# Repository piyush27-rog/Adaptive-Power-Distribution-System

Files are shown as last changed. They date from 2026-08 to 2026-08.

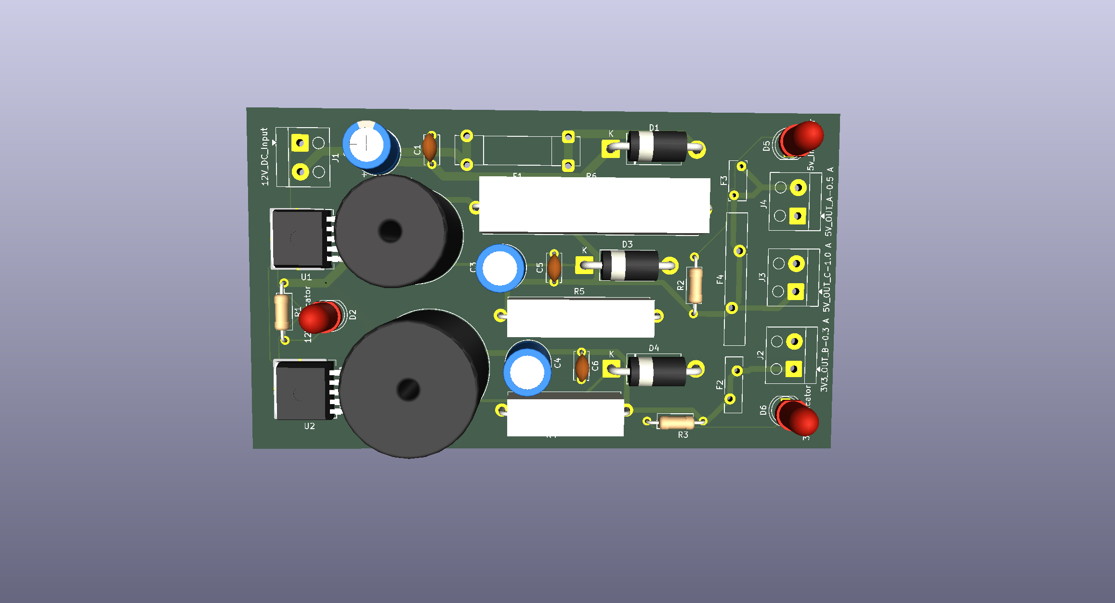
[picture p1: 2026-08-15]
Adaptive-Power-Distribution-System/Images/Adaptive_Power_Distribution_System.png

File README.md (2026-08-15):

# Adaptive Power Distribution System

A 12 V DC power distribution system designed to provide regulated **5 V and 3.3 V outputs** for multiple loads, with input protection and individual output protection.

## Key Specifications

| Parameter | Specification |
|---|---|
| Input | 12 V DC |
| 5 V Output | 5 V / 1.5 A total |
| 3.3 V Output | 3.3 V / 0.3 A |
| Regulators | LM2596S-5 / LM2596S-3.3 |
| Input Protection | 3 A Fuse + Reverse Polarity Protection |
| Output Protection | Individual Polyfuses |
| Simulation | NI Multisim |
| PCB Design | KiCad |

## Highlights

- Dual regulated power rails: **5 V and 3.3 V**
- Reverse-polarity and overcurrent protection
- Individual protected output branches
- Custom schematic and PCB layout
- Simulation and waveform verification
- Engineering calculations and BOM included

## Project Files

- **Multisim** — Circuit simulation
- **KiCad** — Schematic and PCB files
- **Documentation** — BOM, engineering calculations and design explanation
- **Images** — Schematic and PCB views
- **Simulation** — Simulation results

## Tools

**NI Multisim · KiCad**

## Author

**Piyush Thote**

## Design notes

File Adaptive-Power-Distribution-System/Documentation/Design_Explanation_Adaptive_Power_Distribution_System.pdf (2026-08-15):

Adaptive Power Distribution System — Design Explanation

# DESIGN EXPLANATION

## Adaptive Power Distribution System

12 V DC Input • Regulated 5 V & 3.3 V Outputs

### 1. Design Objective

The objective of the Adaptive Power Distribution System is to accept a 12 V DC input and distribute regulated low-voltage power to multiple loads. The design provides a regulated 5 V rail for two loads and a regulated 3.3 V rail for one load, while incorporating input protection, reverse-polarity protection, current protection, power indication and load/status indication.

The design was developed as a complete electronics system: the circuit was simulated in Multisim, the schematic and PCB were developed in KiCad, and the component ratings and power requirements were considered during the design process.

### 2. Overall Circuit Architecture

The system is divided into the following functional blocks:

Block | Function
12 V DC Input | Accepts the external 12 V supply through the input connector.
Input Protection | Provides input overcurrent protection and reverse-polarity protection.
Input Filtering / Energy Storage | Uses bulk and high-frequency capacitors on the protected input rail.
5 V Buck Converter | LM2596S-5.0 generates the regulated 5 V supply.
3.3 V Buck Converter | LM2596S-3.3 generates the regulated 3.3 V supply.
Output Protection | Polyfuses provide resettable overcurrent protection on the output branches.
Power / Load Indicators | LED indicator branches provide visual indication for the input/output rails.
Output Connectors | Distribute the regulated rails to the specified loads.

Power flows from the 12 V input through the input protection stage and then to both buck-converter stages. The converters independently generate the required 5 V and 3.3 V rails. Each output is then distributed through protected branches to the corresponding load connectors.

### 3. Input Protection and Power Entry

### 3.1 Input overcurrent protection

A 3 A fuse is placed in series with the 12 V input. Its purpose is to interrupt the input supply in the event of an abnormal overcurrent condition and to protect the downstream circuitry.

### 3.2 Reverse-polarity protection

A 1N5822 Schottky diode is used in series with the input path for reverse-polarity protection. Under normal polarity the diode permits the supply to reach the protected 12 V rail; if the supply polarity is reversed, the diode blocks the reverse connection.

### 3.3 Input filtering and energy storage

The protected input rail includes a 470 µF bulk capacitor and a 100 nF bypass capacitor. The bulk capacitor provides local energy storage and helps reduce input-voltage variation, while the 100 nF capacitor provides high-frequency bypassing.

### 4. Voltage Regulation Approach

Two independent buck-converter stages are used rather than a single regulator because the system requires two different regulated output voltages.

Stage | Regulator | Output | Required load
5 V stage | LM2596S-5.0 | 5.0 V | 0.5 A + 1.0 A = 1.5 A
3.3 V stage | LM2596S-3.3 | 3.3 V | 0.3 A

The buck topology is appropriate because both required output voltages are lower than the 12 V input. A switching regulator is also better suited to the specified power level than a linear regulator because it can reduce conversion power dissipation.

### 5. Buck-Converter Power Stage

Each LM2596 stage uses the required switching-converter elements: the regulator, a 68 µH inductor, a 1N5822 Schottky diode and a 330 µF output capacitor. The output capacitor supports transient load demand and helps stabilize the regulated rail.

The switching nodes were treated as high-frequency nodes during PCB routing. Their traces were kept short to reduce unnecessary loop area. The higher-current 12 V, 5 V and 3.3 V distribution paths were assigned wider PCB traces, while small-signal connections use narrower traces.

### 6. Output Power Distribution

The 5 V rail supplies two specified loads: Load A at 500 mA and Load C at 1 A. Their combined nominal current is therefore 1.5 A. The 3.3 V rail supplies Load B at 300 mA.

Output | Loads | Total current | Nominal output power
5 V | 500 mA + 1 A | 1.50 A | 7.50 W

3.3 V | 300 mA | 0.30 A | 0.99 W
Total | All specified loads | — | 8.49 W

### 7. Output Current Protection

Resettable polyfuses are placed before the output connectors. This creates separately protected output branches rather than relying only on a common input fuse. The selected branches are intended for the specified 5 V/0.5 A, 5 V/1 A and 3.3 V/0.3 A loads.

The use of separate protected branches improves fault isolation: an abnormal condition on one output branch can be limited without requiring the entire distribution system to be disconnected. The exact hold and trip characteristics depend on the final polyfuse part selected and its operating temperature.

### 8. Power and Load Indication

LED indicator branches are included to provide visual status information for the available rails. Series resistors limit LED current. The indicators are intentionally treated as low-power branches and therefore use narrow signal traces compared with the main power rails.

### 9. Schematic Design Decisions

Decision | Reason
Two independent buck stages | Required 5 V and 3.3 V outputs are independently regulated.
Schottky input diode | Provides simple reverse-polarity protection with relatively low forward drop.
3 A input fuse | Provides input overcurrent protection with margin over the expected normal input current.
470 µF input capacitor | Provides bulk energy storage and input smoothing.
100 nF bypass capacitors | Provides high-frequency local bypassing.
330 µF output capacitors | Supports output transients and reduces output ripple.
Output polyfuses | Provides resettable branch-level current protection.
Separate output connectors | Allows independent distribution of the required rails to loads.

### 10. PCB Architecture

The PCB was organized so that the power-entry and protection section is separated from the two converter stages and the output connectors. The inductors, Schottky diodes and output capacitors are kept close to their respective LM2596 stages to keep the switching paths compact.

High-current power nets were routed with wider traces. The 12 V main path uses approximately 1.5 mm, the 5 V main path approximately 1.0–1.5 mm depending on the branch, and the 3.3 V main path approximately 1.0 mm. Small signal paths use approximately 0.2–0.25 mm. A copper ground plane is used to provide a low-impedance return path and simplify ground distribution.

The completed PCB concept also includes output polyfuses, output connectors and status indicators, providing a compact power-distribution arrangement rather than a collection of independent regulator circuits.

### 11. Simulation Approach

The circuit was simulated in Multisim under the specified resistive load conditions. The load resistances were calculated from R = V/I: 10 Ω for 5 V/500 mA, 5 Ω for 5 V/1 A, and 11 Ω for 3.3 V/300 mA.

Voltage probes and current measurements were used to verify the input and regulated output behavior. An oscilloscope was also used to observe the output waveform and settling behavior. The simulation confirmed that the converter stages reach the intended regulated output levels under the modeled load conditions.

During simulation, a long real-time observation was initially noticed at the output measurement display. The oscilloscope measurement showed the electrical response occurring on a much shorter simulation-time scale, so the long timer observation was treated as a simulation/display timing issue rather than as a physical one-minute-plus regulator startup requirement.

### 12. Design Verification

Item | Target / requirement | Design implementation
Input voltage | 12 V DC | 12 V DC input connector
5 V output | 5 V regulated | LM2596S-5.0
3.3 V output | 3.3 V regulated | LM2596S-3.3
5 V load capacity | 1.5 A total | Dedicated 5 V buck stage
3.3 V load capacity | 0.3 A | Dedicated 3.3 V buck stage
Input protection | Required | 3 A fuse + 1N5822
Current protection | Required | Output polyfuses
Power indication | Required | LED indicators
Safe power distribution | Required | Protected individual output branches

### 13. Limitations

- Reverse-polarity protection using a series Schottky diode introduces a forward-voltage drop and associated power loss.
- Exact converter efficiency and thermal performance depend on the selected LM2596 implementation, inductor, diode, capacitors, PCB copper area and operating temperature.

- Polyfuse behavior is temperature- and time-dependent; the final part's hold/trip curves should be checked against the intended loads.
- The Multisim model does not replace hardware validation. Real measurements should be performed for ripple, efficiency, temperature rise, startup behavior and protection response.
- The design is intended for the specified low-voltage loads; higher loads should not be connected without rechecking regulator current capability, thermal performance, traces, connectors and protection ratings.

### 14. Possible Improvements

- Replace the series reverse-polarity diode with an ideal-diode MOSFET arrangement to reduce input voltage drop and conduction loss.
- Use regulators with integrated thermal/current protection and optimize the power-stage components using the exact regulator datasheet recommendations.
- Add dedicated input and output transient protection such as TVS protection if the real operating environment contains significant surges or cable transients.
- Add test points for 12 V protected, 5 V, 3.3 V and GND to simplify production testing and debugging.
- Add mounting holes and mechanical keep-outs for enclosure integration.
- Validate the finished PCB experimentally using electronic loads and a thermal camera or thermocouple, then update the efficiency and thermal calculations with measured data.
- Consider separate status indicators for each protected output branch if more detailed load-status information is required.

### 15. Conclusion

The final design implements a compact 12 V DC power-distribution system with independently regulated 5 V and 3.3 V outputs. The architecture combines buck conversion, input protection, reverse-polarity protection, branch-level resettable current protection, filtering, indication and a dedicated PCB layout. The calculated full-load output requirement is 8.49 W, consisting of 7.50 W on the 5 V rail and 0.99 W on the 3.3 V rail. The completed schematic, Multisim simulation and PCB were developed around these requirements.

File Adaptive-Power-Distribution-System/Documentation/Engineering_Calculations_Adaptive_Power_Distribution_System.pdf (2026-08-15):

Adaptive Power Distribution System — Engineering Calculations

# ENGINEERING CALCULATIONS

## Adaptive Power Distribution System

12 V DC Input • Regulated 5 V & 3.3 V Outputs

### 1. Purpose and Design Basis

Purpose. This document presents the calculations used to size the loads, determine output power and current, assess regulator requirements, justify protection, and consider power loss and thermal behavior.

Assessment basis. The assessment specifies a 12 V DC input, regulated 5 V and 3.3 V outputs, Load A = 5 V/500 mA, Load B = 3.3 V/300 mA, and Load C = 5 V/1 A. It also asks for calculations covering current, power, losses, regulator requirements and thermal considerations.

Implemented design. The completed design uses LM2596S-5.0 and LM2596S-3.3 buck-converter stages. The Multisim loads are represented by 10 Ω, 11 Ω and 5 Ω resistors.

### 2. Design Input and Load Requirements

Load/Rail | Voltage | Current | Equivalent R | Power
Load A | 5.0 V | 0.50 A | 10 Ω | 2.50 W
Load B | 3.3 V | 0.30 A | 11 Ω | 0.99 W
Load C | 5.0 V | 1.00 A | 5 Ω | 5.00 W
5 V total | 5.0 V | 1.50 A | — | 7.50 W
3.3 V total | 3.3 V | 0.30 A | — | 0.99 W
Total output | — | — | — | 8.49 W

### 3. Load Resistance Calculations

### 3.1 Load A — 5 V, 500 mA

R = V / I = 5 / 0.5 = 10 Ω

P = V × I = 5 × 0.5 = 2.50 W

The simulation therefore uses 10 Ω. The resistor should have a practical power rating above 2.50 W.

### 3.2 Load B — 3.3 V, 300 mA

R = 3.3 / 0.3 = 11 Ω

P = 3.3 × 0.3 = 0.99 W

The simulation uses 11 Ω. A 1 W resistor is the minimum nominal rating; a higher rating provides additional margin.

### 3.3 Load C — 5 V, 1 A

R = 5 / 1 = 5 Ω

P = 5 × 1 = 5.00 W

The simulation uses 5 Ω. The resistor should be rated above 5 W for practical operation.

### 4. Output Current and Power Requirements

4.1 5 V rail
I₅V,total = 0.50 + 1.00 = 1.50 A

P₅V = 5 × 1.50 = 7.50 W

4.2 3.3 V rail
I₃.₃V,total = 0.30 A

P₃.₃V = 3.3 × 0.30 = 0.99 W

### 4.3 Total regulated output

P_OUT,total = 7.50 + 0.99 = 8.49 W

Therefore, the system is designed to deliver approximately 8.49 W when all specified loads operate simultaneously at nominal voltage and current.

### 5. Input Power and Current

The assessment does not specify a guaranteed converter efficiency. Therefore, exact input current and loss should be taken from the final simulation or hardware measurement. The governing relationships are:

P_IN = P_OUT / η

I_IN = P_IN / V_IN

Assumed η | Input power | Input current @ 12 V | Estimated loss
80% | 10.61 W | 0.884 A | 2.12 W
85% | 9.99 W | 0.833 A | 1.50 W
90% | 9.43 W | 0.786 A | 0.94 W

Reporting note: The efficiency cases above are engineering scenarios, not measured values. Replace them with actual Multisim input measurements if available.

### 6. Regulator Requirement

Regulator | Nominal output | Required load current | Topology | Requirement
LM2596S-5.0 | 5.0 V | 1.50 A | Buck | Must support ≥1.50 A
LM2596S-3.3 | 3.3 V | 0.30 A | Buck | Must support ≥0.30 A

A buck converter is appropriate because both required output voltages are lower than the 12 V input. Compared with a linear regulator, a switching buck topology substantially reduces conversion dissipation at these load currents.

### 7. Protection Calculations

### 7.1 Input fuse

The design uses a 3 A input fuse. Using the 80% illustrative efficiency case:

I_IN ≈ 10.61 / 12 = 0.884 A

3 A / 0.884 A ≈ 3.39

Thus the selected fuse is above the estimated normal full-load input current while providing a protective limit for abnormal input overcurrent. Final fuse selection should also consider startup/inrush current and the selected fuse's time-current characteristic.

### 7.2 Output protection

Branch | Specified load | Protection | Purpose
5 V / Load A | 0.50 A | 0.5 A polyfuse | Branch overcurrent protection
5 V / Load C | 1.00 A | 1.0 A polyfuse | Branch overcurrent protection
3.3 V / Load B | 0.30 A | Low-current polyfuse | Branch overcurrent protection

Polyfuse hold/trip behavior depends on the exact part, ambient temperature and time; the final BOM should therefore reference the selected manufacturer's datasheet.

### 8. Passive Components and Energy Storage

Input bulk capacitor. 470 µF is used on the protected 12 V rail for local energy storage and input-voltage smoothing.

High-frequency bypass. 100 nF capacitors provide local high-frequency bypassing around the converter stages.

Output capacitors. 330 µF capacitors are used on the 5 V and 3.3 V rails to support transient load demand and reduce ripple.

Inductors. 68 µH inductors are used in both buck stages. The exact final component should be verified for saturation current, RMS current and voltage rating against the chosen LM2596 implementation.

### 9. Thermal Considerations

The specified load consumes 8.49 W at the regulated outputs. Converter heat is determined by actual input power:

P_LOSS = P_IN − P_OUT

For reference, the combined converter loss would be about 2.12 W at 80% efficiency, 1.50 W at 85%, or 0.94 W at 90%. These are scenarios rather than measured results.

The PCB should provide adequate copper around the regulator power and ground connections, keep high-current paths short and wide, and provide suitable clearance and airflow around the regulators and power resistors. The 5 Ω simulation load dissipates 5 W and therefore requires a suitably rated power resistor.

### 10. Voltage Regulation Verification

The Multisim simulation is used to verify the intended 5.0 V and 3.3 V steady-state outputs. Insert the final steady-state probe values from the simulation in the table below.

Rail | Nominal | Final simulated value | Error
5 V | 5.0 V | Insert Multisim value | (Measured−5)/5 × 100%
3.3 V | 3.3 V | Insert Multisim value | (Measured−3.3)/3.3 × 100%

The earlier Multisim oscilloscope check showed the output reaching the regulated region on a much shorter simulation timescale than the long real-time observation. Therefore, the long timer observation should not be used as the circuit's actual electrical settling-time specification.

### 11. Summary of Key Calculations

Parameter | Calculated value
5 V total current | 1.50 A
3.3 V total current | 0.30 A
5 V output power | 7.50 W
3.3 V output power | 0.99 W
Total output power | 8.49 W
Load A | 10 Ω, 2.50 W
Load B | 11 Ω, 0.99 W
Load C | 5 Ω, 5.00 W
Input fuse | 3 A

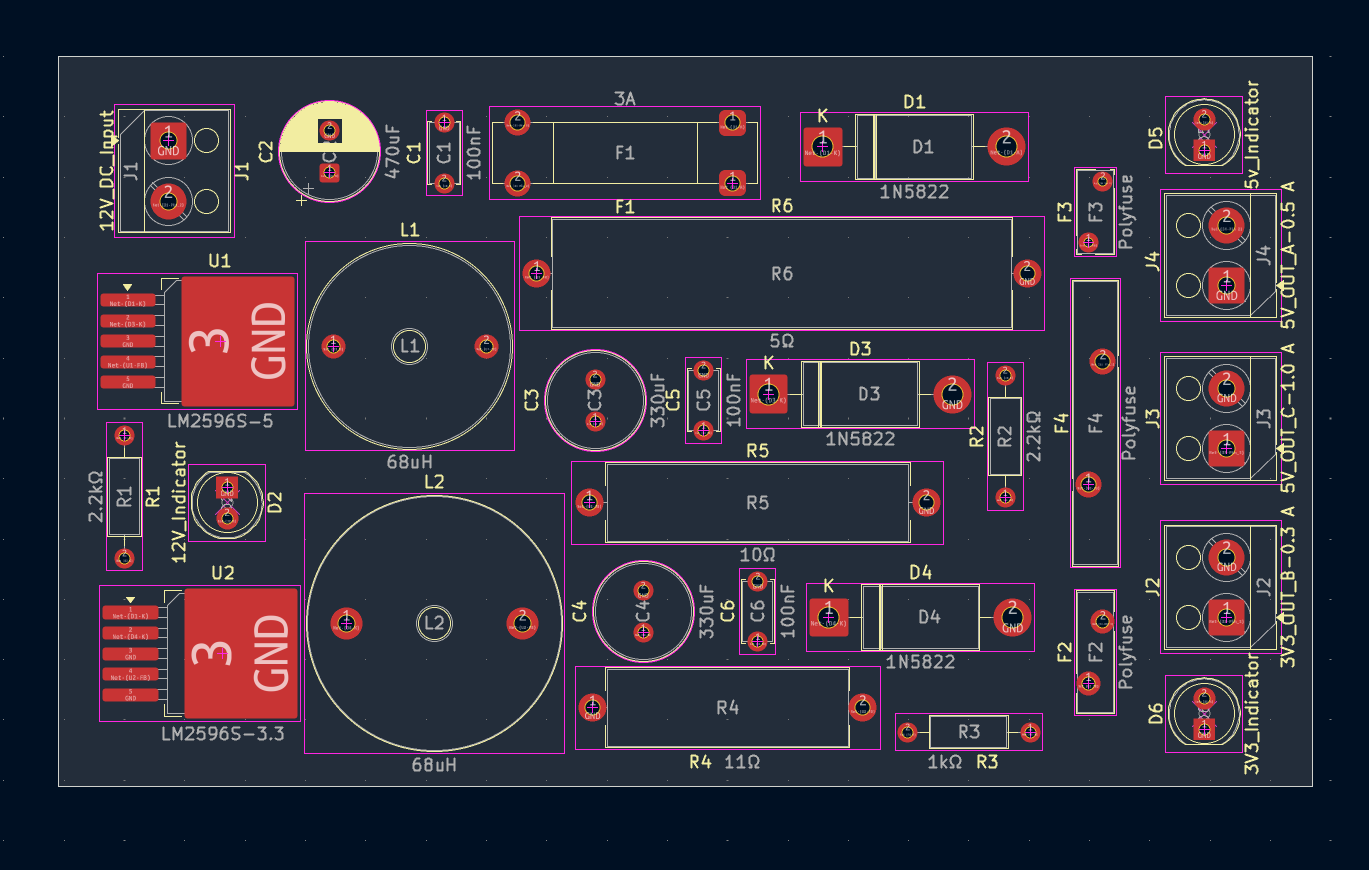
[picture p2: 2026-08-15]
Adaptive-Power-Distribution-System/Images/PCB_Layout.png

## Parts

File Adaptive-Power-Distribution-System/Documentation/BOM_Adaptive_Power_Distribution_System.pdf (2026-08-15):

Adaptive Power Distribution System — Verified BOM

# BILL OF MATERIALS (BOM) — VERIFIED

## Adaptive Power Distribution System

Verified against the supplied final schematic screenshots

## 1. Verification Basis

The component reference designators and values below were checked directly against the three supplied schematic screenshots: the Protected 12 V section, the +5 V rail, and the +3.3 V rail. This verification corrects the previous BOM where the values of R2 and R3 were not matched to the final schematic.

## 2. Verified BOM

No. | Ref. | Value / Rating | Component | Qty. | Package | Function
1 | J1 | 12V_DC_Input | 2-pin connector | 1 | THT | 12 V input
2 | F1 | 3 A | Fuse | 1 | THT | Main input protection
3 | D1 | 1N5822 | Schottky diode | 1 | THT | Reverse-polarity protection
4 | C1 | 100 nF | Capacitor | 1 | THT | Protected 12 V bypass
5 | C2 | 470 µF | Electrolytic capacitor | 1 | THT | Protected 12 V bulk capacitor
6 | R1 | 2.2 kΩ | Resistor | 1 | THT axial | 12 V indicator current limiting
7 | D2 | 12V_Indicator | LED | 1 | THT LED | 12 V status indication
8 | U1 | LM2596S-5 | Buck regulator | 1 | TO-263 / D2PAK | 5 V regulator
9 | L1 | 68 µH | Power inductor | 1 | THT | 5 V buck stage
10 | D3 | 1N5822 | Schottky diode | 1 | THT | 5 V buck diode
11 | C3 | 330 µF | Electrolytic capacitor | 1 | THT | 5 V output capacitor
12 | C5 | 100 nF | Capacitor | 1 | THT | 5 V bypass
13 | R2 | 2.2 kΩ | Resistor | 1 | THT axial | 5 V indicator current limiting
14 | D5 | 5V_Indicator | LED | 1 | THT LED | 5 V status indication
15 | R5 | 10 Ω | Power resistor | 1 | High-power THT | 5 V / 0.5 A load model

16 | F3 | 0.5 A Polyfuse | Resettable fuse | 1 | THT | 5 V / 0.5 A output protection
17 | R6 | 5 Ω | Power resistor | 1 | High-power THT | 5 V / 1 A load model
18 | F4 | 1.0 A Polyfuse | Resettable fuse | 1 | THT | 5 V / 1 A output protection
19 | J4 | 5V_OUT_A–0.5 A | 2-pin connector | 1 | THT | 5 V / 0.5 A output
20 | J3 | 5V_OUT_C–1.0 A | 2-pin connector | 1 | THT | 5 V / 1 A output
21 | U2 | LM2596S-3.3 | Buck regulator | 1 | TO-263 / D2PAK | 3.3 V regulator
22 | L2 | 68 µH | Power inductor | 1 | THT | 3.3 V buck stage
23 | D4 | 1N5822 | Schottky diode | 1 | THT | 3.3 V buck diode
24 | C4 | 330 µF | Electrolytic capacitor | 1 | THT | 3.3 V output capacitor
25 | C6 | 100 nF | Capacitor | 1 | THT | 3.3 V bypass
26 | R3 | 1 kΩ | Resistor | 1 | THT axial | 3.3 V indicator current limiting
27 | D6 | 3V3_Indicator | LED | 1 | THT LED | 3.3 V status indication
28 | R4 | 11 Ω | Power resistor | 1 | High-power THT | 3.3 V / 0.3 A load model
29 | F2 | 0.3 A Polyfuse | Resettable fuse | 1 | THT | 3.3 V / 0.3 A output protection
30 | J2 | 3V3_OUT_B–0.3 A | 2-pin connector | 1 | THT | 3.3 V / 0.3 A output

## 3. Critical Designator / Value Verification

Reference | Verified value | Where verified
R1 | 2.2 kΩ | Protected 12 V section
R2 | 2.2 kΩ | 5 V rail
R3 | 1 kΩ | 3.3 V rail
R4 | 11 Ω | 3.3 V load
R5 | 10 Ω | 5 V / 0.5 A load
R6 | 5 Ω | 5 V / 1 A load
C1 | 100 nF | Protected 12 V section
C2 | 470 µF | Protected 12 V section

C3 | 330 µF | 5 V rail
C4 | 330 µF | 3.3 V rail
C5 | 100 nF | 5 V rail
C6 | 100 nF | 3.3 V rail
D1 | 1N5822 | Input protection
D3 | 1N5822 | 5 V buck stage
D4 | 1N5822 | 3.3 V buck stage
D2 | 12V_Indicator | 12 V status LED
D5 | 5V_Indicator | 5 V status LED
D6 | 3V3_Indicator | 3.3 V status LED
F1 | 3 A | Input fuse
F2 | Polyfuse, 0.3 A branch | 3.3 V output
F3 | Polyfuse, 0.5 A branch | 5 V / 0.5 A output
F4 | Polyfuse, 1.0 A branch | 5 V / 1.0 A output

## 4. Output Protection Mapping

Connector | Rail | Load | Protection
J2 | 3.3 V | 0.3 A | F2 — 0.3 A polyfuse
J4 | 5 V | 0.5 A | F3 — 0.5 A polyfuse
J3 | 5 V | 1.0 A | F4 — 1.0 A polyfuse

## 5. Component Count Summary

Category | Quantity
LM2596 regulators | 2
68 µH inductors | 2
1N5822 diodes | 3
Electrolytic capacitors | 3 (470 µF ×1, 330 µF ×2)
100 nF capacitors | 3
LED indicators | 3
LED resistors | 3 (2.2 kΩ ×2, 1 kΩ ×1)
Load resistors | 3 (10 Ω, 11 Ω, 5 Ω)

Fuses / polyfuses | 4 (3 A ×1, 0.3 A ×1, 0.5 A ×1, 1 A ×1)
Connectors | 4 (J1–J4)

## 6. Notes Before Final Submission

- R2 is 2.2 kΩ, not 1 kΩ. R3 is 1 kΩ. These values now match the supplied final schematic.
- The three 100 nF capacitors are C1, C5 and C6.
- The two 330 µF capacitors are C3 and C4; the 470 µF input capacitor is C2.
- The three 1N5822 diodes are D1, D3 and D4. D2, D5 and D6 are the LED indicators.
- The polyfuse mapping is F2 = 3.3 V/0.3 A, F3 = 5 V/0.5 A and F4 = 5 V/1 A.
- Exact manufacturer MPNs for generic resistors, capacitors, connectors and polyfuses should only be added after the actual procurement parts are selected.

## 7. Regulator Package Reference

The LM2596S-5.0 and LM2596S-3.3 variants are available in TI's 5-pin DDPAK/TO-263 package. The exact footprint used on the PCB should therefore match the purchased regulator package. TI's current documentation lists LM2596S-3.3/NOPB and LM2596S-5.0/NOPB as 5-pin DDPAK/TO-263 devices.

Reference: Texas Instruments LM2596 datasheet.

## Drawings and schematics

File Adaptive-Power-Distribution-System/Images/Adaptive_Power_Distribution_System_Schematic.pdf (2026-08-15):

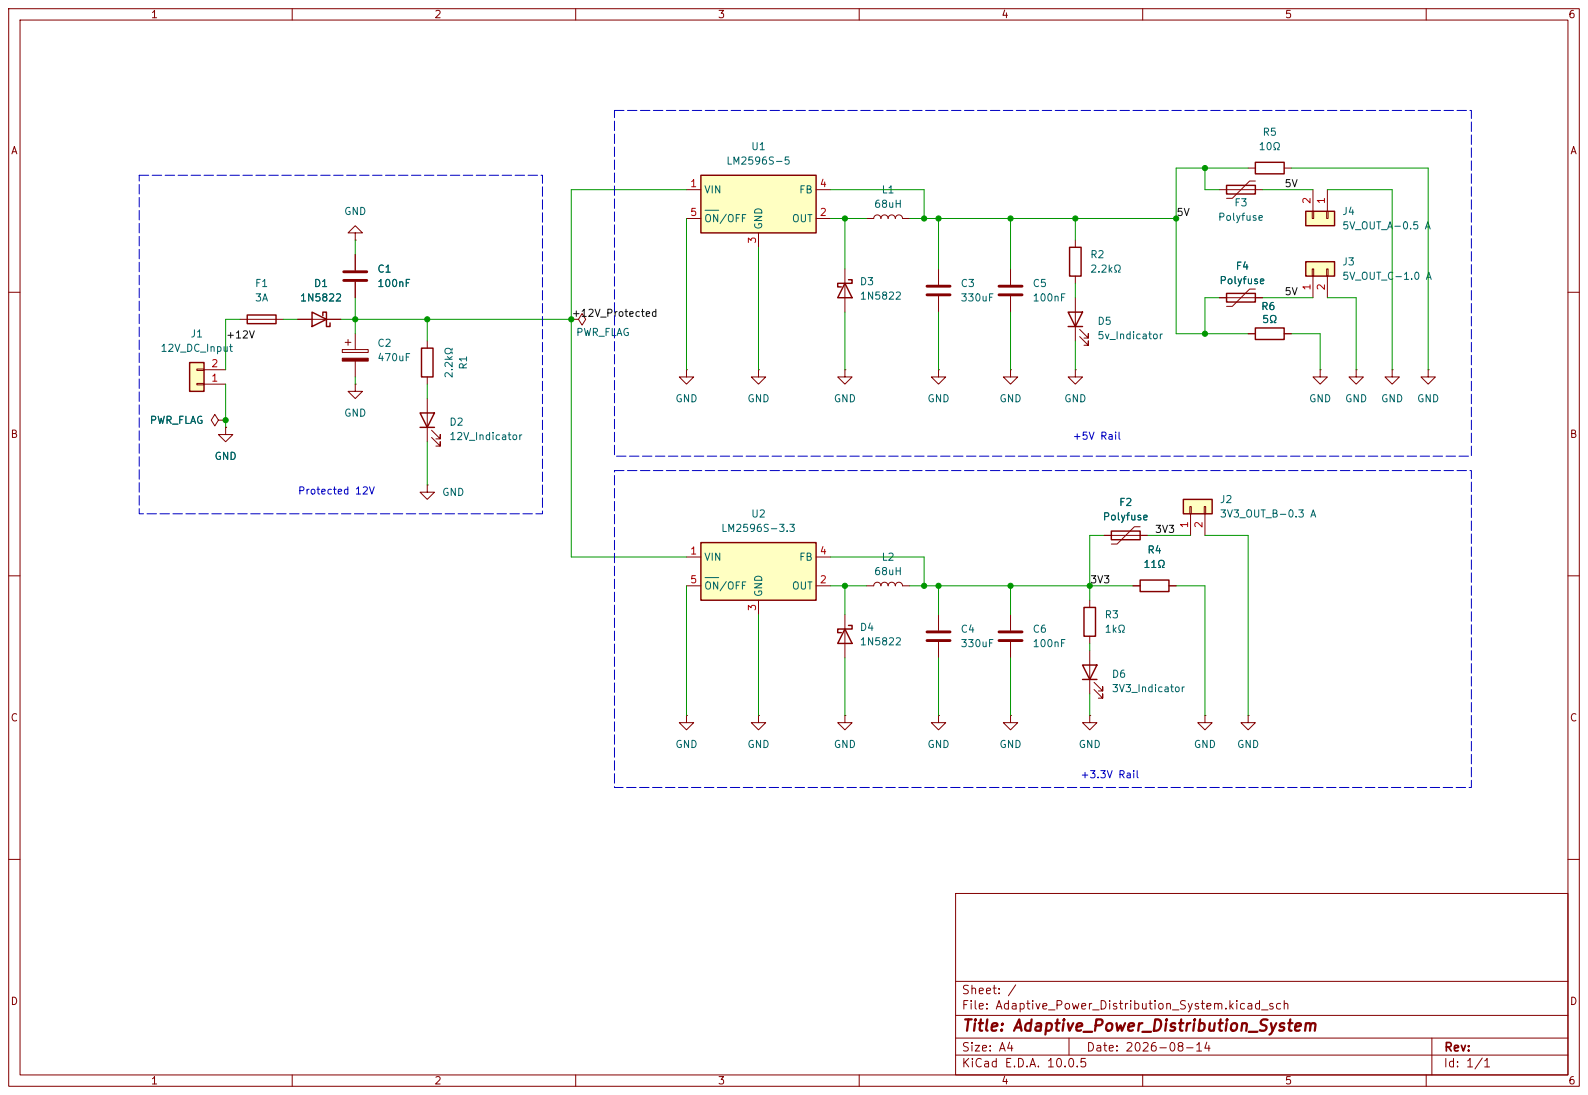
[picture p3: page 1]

Size: A4 | Rev:
KiCad E.D.A. 10.0.5 | Id: 1/1

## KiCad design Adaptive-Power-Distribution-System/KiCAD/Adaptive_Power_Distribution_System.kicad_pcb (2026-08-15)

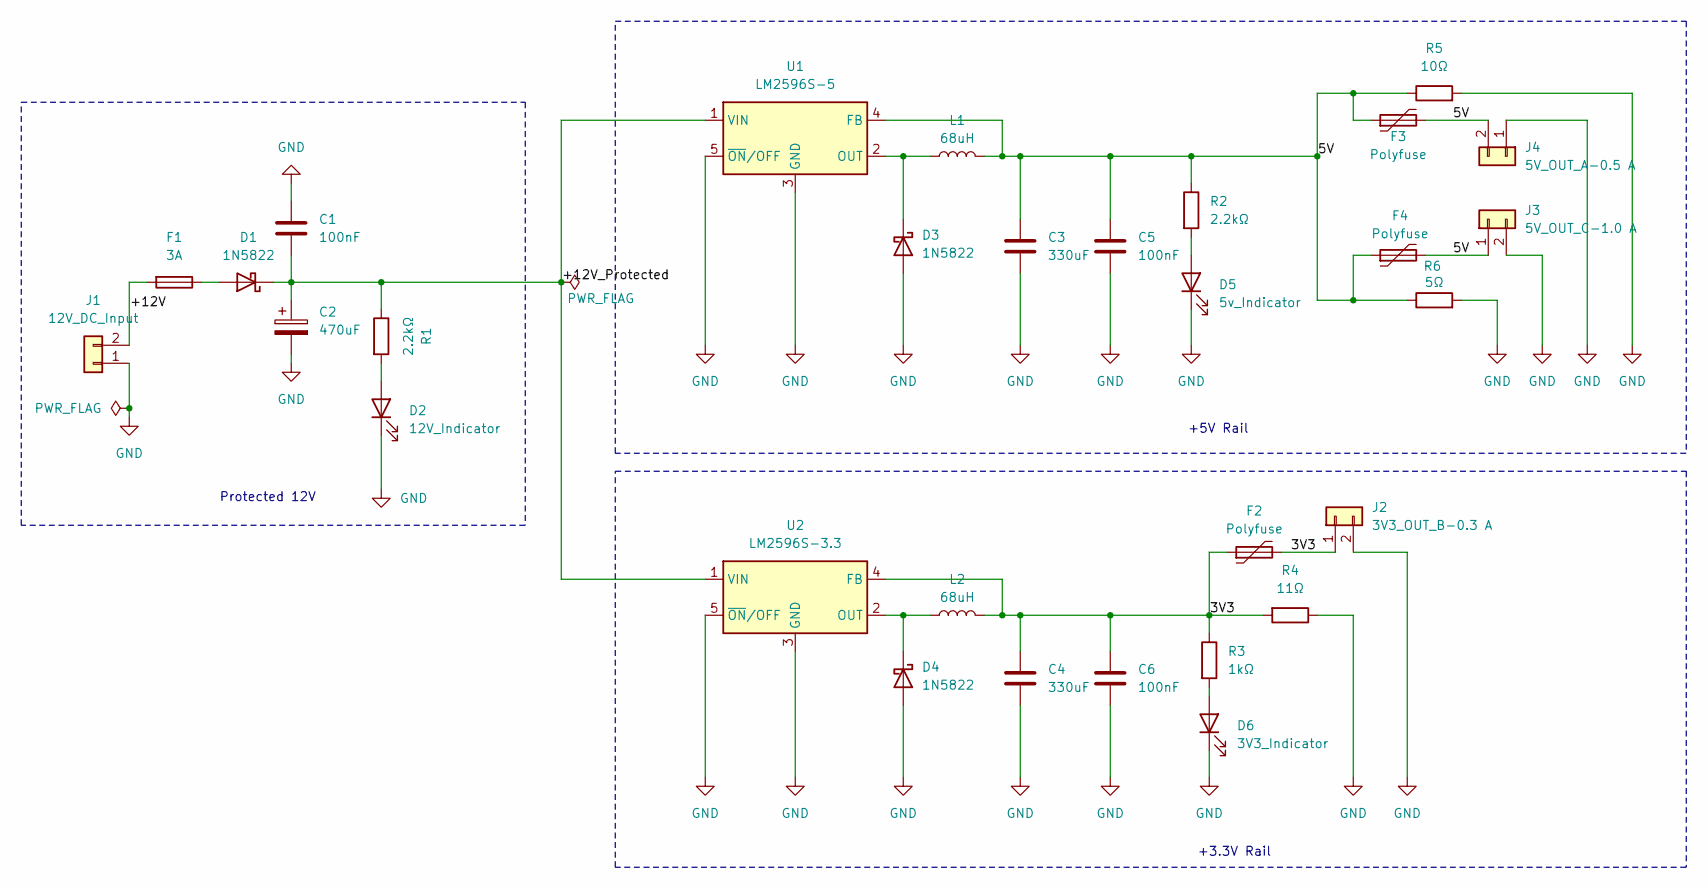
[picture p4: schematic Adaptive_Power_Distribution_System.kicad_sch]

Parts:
C1, C5, C6: 100nF; C_Disc_D5.0mm_W2.5mm_P5.00mm
C2: 470uF; CP_Radial_D8.0mm_P3.50mm
C3, C4: 330uF; C_Radial_D8.0mm_H11.5mm_P3.50mm
D1, D3, D4: 1N5822; D_DO-201AD_P15.24mm_Horizontal
D2: 12V_Indicator; LED_D5.0mm
D5: 5v_Indicator; LED_D5.0mm
D6: 3V3_Indicator; LED_D5.0mm
F1: 3A; Fuseholder_Clip-5x20mm_Bel_FC-203-22_Lateral_P17.80x5.00mm_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
F2: Polyfuse; Fuse_Bourns_MF-RHT400
F3: Polyfuse; Fuse_Bourns_MF-RHT070
F4: Polyfuse; Fuse_Bourns_MF-RHT1300
J1: 12V_DC_Input; Altech_AK100_1x02_P5.00mm
J2: 3V3_OUT_B-0.3 A; Altech_AK100_1x02_P5.00mm
J3: 5V_OUT_C-1.0 A; Altech_AK100_1x02_P5.00mm
J4: 5V_OUT_A-0.5 A; Altech_AK100_1x02_P5.00mm
L1: 68uH; L_Radial_D16.8mm_P12.70mm_Vishay_IHB-1
L2: 68uH; L_Radial_D21.0mm_P14.61mm_Vishay_IHB-2
R1, R2: 2.2kΩ; R_Axial_DIN0207_L6.3mm_D2.5mm_P10.16mm_Horizontal
R3: 1kΩ; R_Axial_DIN0207_L6.3mm_D2.5mm_P10.16mm_Horizontal
R4: 11Ω; R_Axial_Power_L20.0mm_W6.4mm_P22.40mm
R5: 10Ω; R_Axial_Power_L25.0mm_W6.4mm_P27.94mm
R6: 5Ω; R_Axial_Power_L38.0mm_W9.0mm_P40.64mm
U1: LM2596S-5; TO-263-5_TabPin3
U2: LM2596S-3.3; TO-263-5_TabPin3

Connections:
/3V3: C4.1, C6.1, F2.1, F2.2, J2.1, L2.2, R3.1, R4.2, U2.4 (FB)
/5V: C3.1, C5.1, F3.1, F3.2, F4.1, F4.2, J3.1, J4.2, L1.2, R2.1, R5.1, R6.1, U1.4 (FB)
/+12V: F1.2, J1.2
/+12V_Protected: C1.2, C2.1, D1.1 (K), R1.1, U1.1 (VIN), U2.1 (VIN)
GND: C1.1, C2.2, C3.2, C4.2, C5.2, C6.2, D2.1 (K), D3.2 (A), D4.2 (A), D5.1 (K), D6.1 (K), J1.1, J2.2, J3.2, J4.1, R4.1, R5.2, R6.2, U1.3 (GND), U1.5 (~ON/OFF), U2.3 (GND), U2.5 (~ON/OFF)
unnamed: D1.2 (A), F1.1
unnamed: D2.2 (A), R1.2
unnamed: D3.1 (K), L1.1, U1.2 (OUT)
unnamed: D4.1 (K), L2.1, U2.2 (OUT)
unnamed: D5.2 (A), R2.2
unnamed: D6.2 (A), R3.2

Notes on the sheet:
+5V Rail
Protected 12V
+3.3V Rail

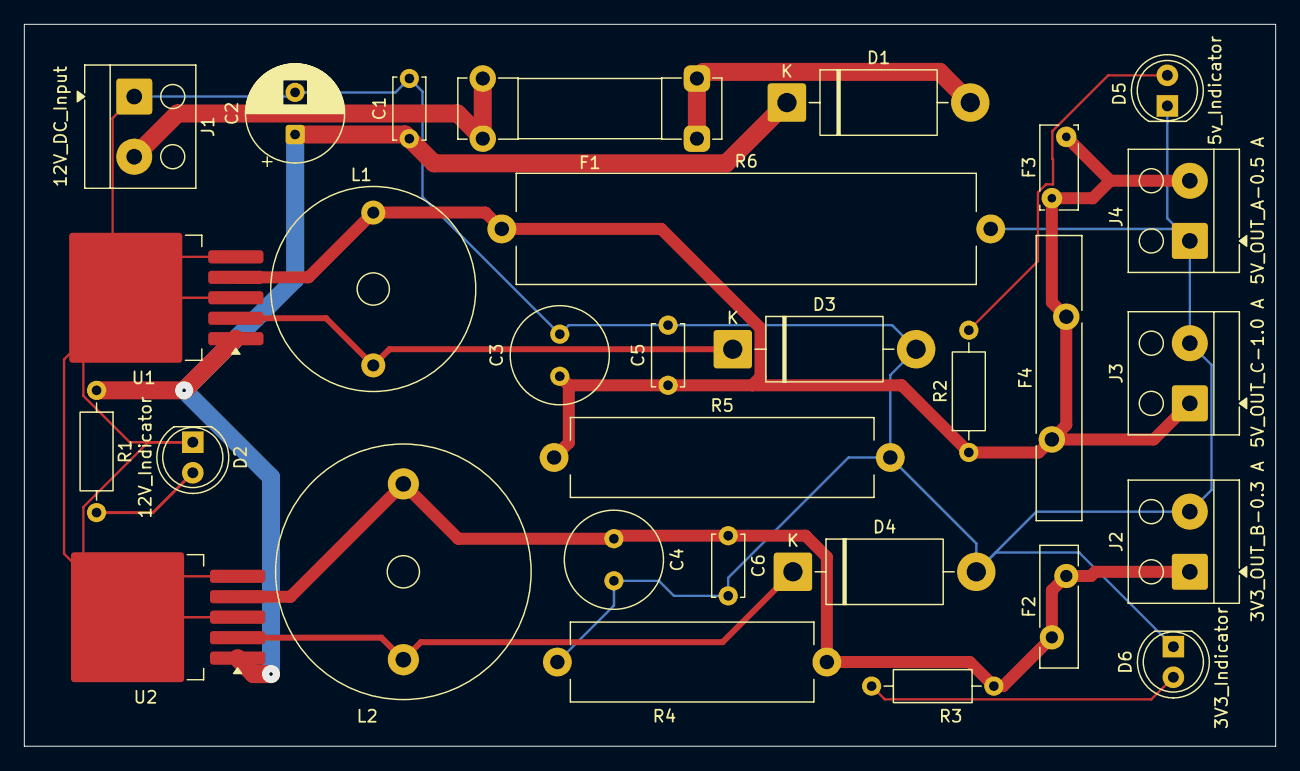
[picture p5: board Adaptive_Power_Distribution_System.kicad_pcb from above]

Board: 2 copper layers, 104.0 x 60.0 mm, 30 parts (0 on the bottom side), 11 nets.

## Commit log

2026-08-15 Create README.md for Adaptive Power Distribution System
    Added detailed project description, specifications, and author information to README.md.
2026-08-15 Create README.md for Adaptive Power Distribution System
    Added detailed project documentation including specifications, highlights, project files, tools used, and author information.
